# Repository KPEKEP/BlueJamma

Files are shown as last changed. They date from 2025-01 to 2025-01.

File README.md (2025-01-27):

# Arcade Bluetooth Controller Adapter "BlueJamma"

## Overview
This project provides a hardware and software solution to add Bluetooth gamepad support to Jamma/Chamma arcade boards (like Pandora Box), while maintaining the original physical controls functionality. The adapter allows connecting up to 2 Bluetooth gamepads simultaneously with the existing control panel.

The device is built around the ESP32-C3 SuperMini development board, which provides an excellent balance of size, features, and cost. The control program is based on the BluePad32 library and can be found in the `sketch` folder of this repository.

## Features
- Supports up to 2 Bluetooth gamepads simultaneously
- Maintains original control panel functionality
- Compatible with Jamma/Chamma arcade boards
- Easy installation and setup
- Open-source hardware and software

## Hardware
The project uses the ESP32-C3 SuperMini form factor for its compact size and built-in USB capabilities. A complete list of required components and materials can be found in the interactive [Bill of Materials](bom/ibom.html).

The PCB design incorporates elements from the [JammaKludge project](https://github.com/estechnical/jammakludge) by estechnical, which provided valuable reference for the Jamma connector implementation.

## PCB Design
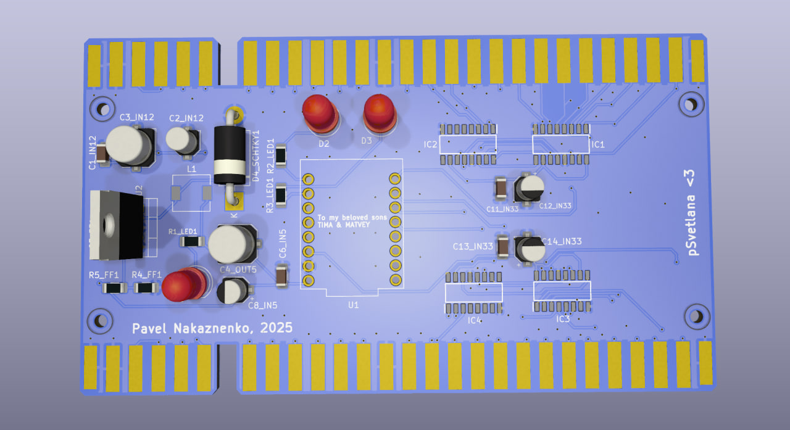
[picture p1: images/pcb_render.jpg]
PCB Front Render

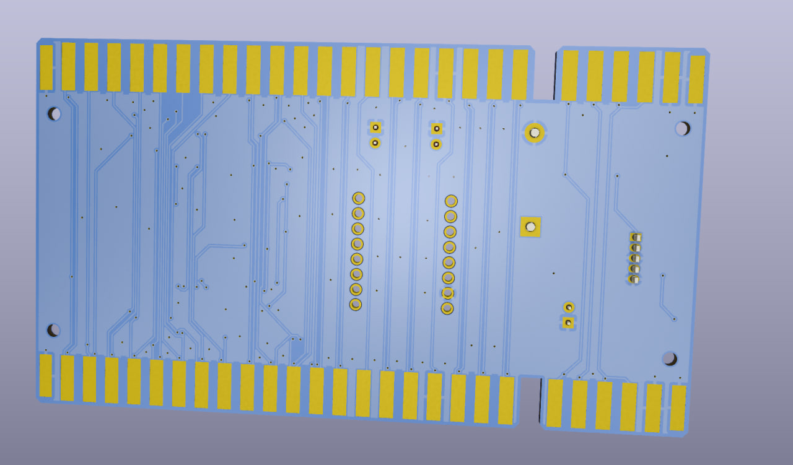
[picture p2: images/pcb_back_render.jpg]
PCB Back Render


## Enclosure Design
Check out the 3D render of the enclosure design:
https://github.com/KPEKEP/BlueJamma/raw/main/enclosure/export/rc3/rc3_v1.avi

STEP files for the enclosure are available in the [enclosure/export/rc3/](enclosure/export/rc3/) folder.

## Assembled Device
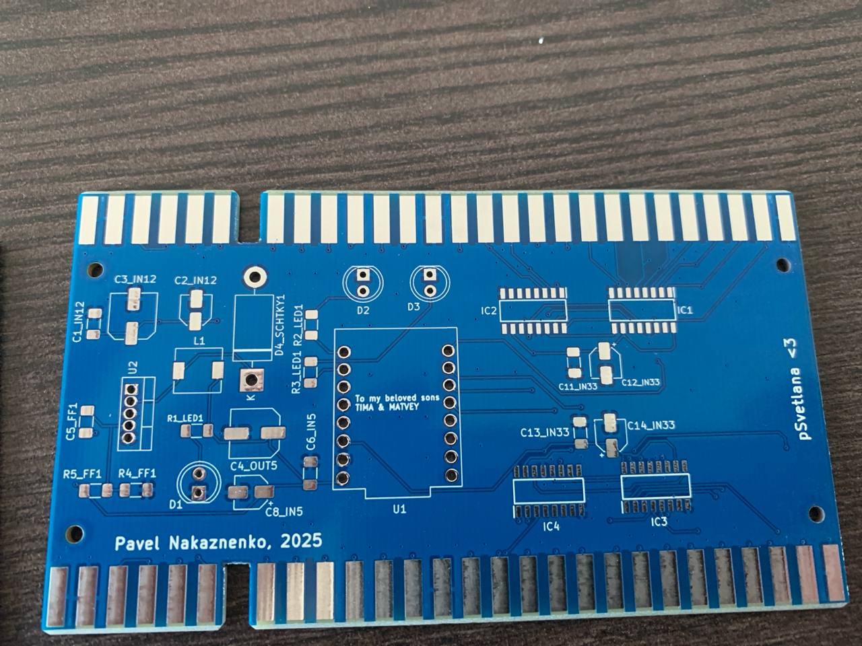
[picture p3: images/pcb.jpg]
Manufactured PCB

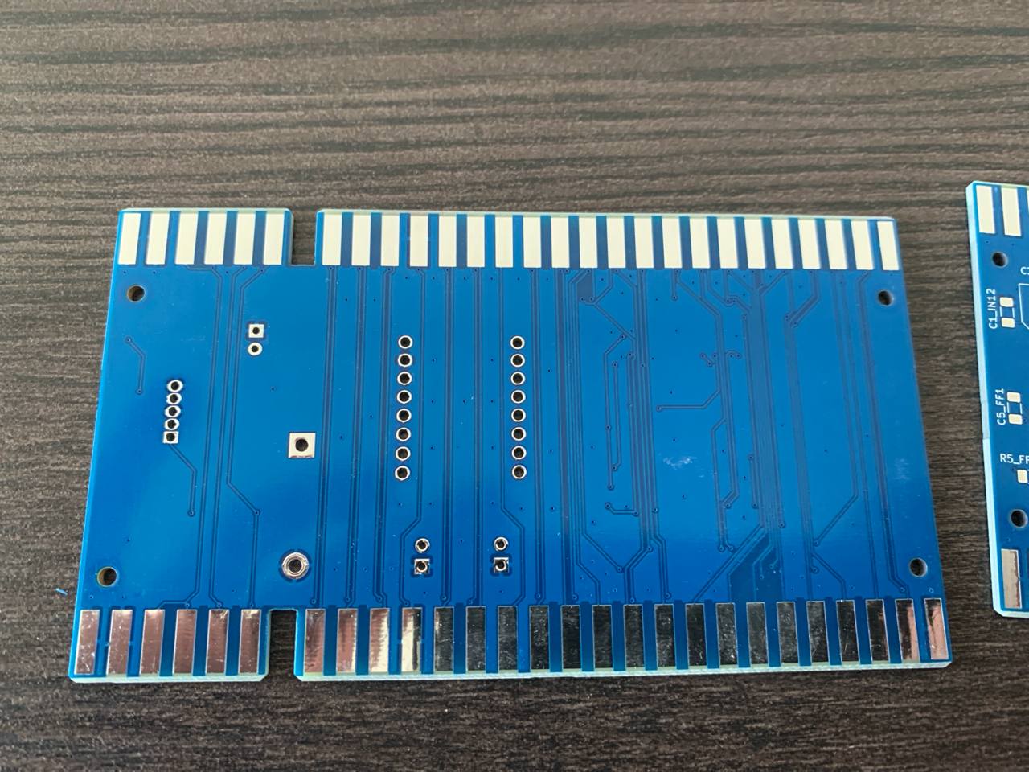
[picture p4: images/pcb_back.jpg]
Manufactured PCB Back

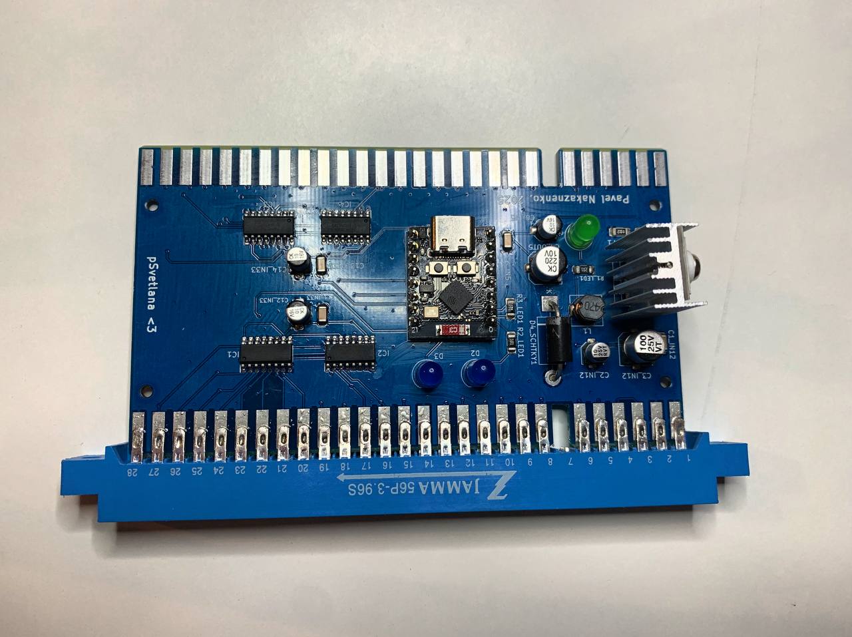
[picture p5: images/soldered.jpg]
Soldered Device

Assembled device: https://github.com/KPEKEP/BlueJamma/raw/main/images/assembled.MOV

Watch a demo of the device working with Bluetooth controllers:
https://github.com/KPEKEP/BlueJamma/raw/main/images/demo.mp4

## Risk Disclaimer
### ATTENTION: The device was tested only with Pandora Box, which is a Chamma board. Jamma boards are not tested yet.
### Chamma and Jamma compatibility
### IMPORTANT: The additional kicker harnesses are not supported yet.

BlueJamma was designed to be a pass-through between the arcade board and physical controls or whatever is connected next. When no input is coming from gamepads, regardless of their connection status, the system behaves as it would be a straight connection between the arcade board and physical controllers.
If an arcade board has Chamma (6-button), or regular Jamma (3-button) interface, it should work.
Please refer to the image of the layout below (side by side of top and bottom side of the PCB) and pay attention to the traces between 25,26,27,C,D,E on the right side of the PCB.

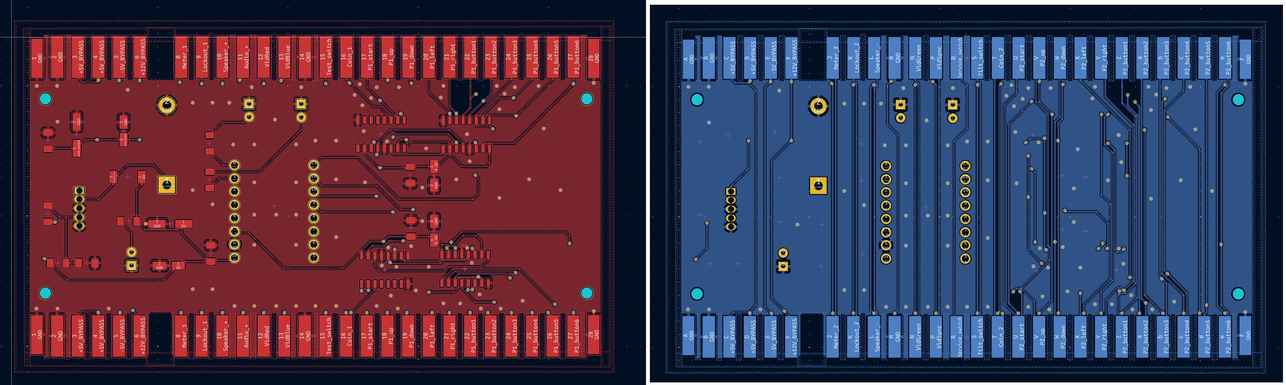
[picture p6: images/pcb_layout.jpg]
PCB Layout


**USE AT YOUR OWN RISK**: The hardware and software in this project are provided "as is", without warranty of any kind, express or implied. The creators and contributors of this project accept no responsibility or liability for any damage, injury, or loss resulting from the use of this project's hardware, software, or documentation.

- We are not responsible for any damage to your arcade board, control panel, or other equipment
- Modify your hardware at your own risk
- Always verify connections and power requirements before use

### Components Attribution
This project uses:
- Open-source libraries and components, all properly credited in the source code
- Originally written code and hardware designs
- Third-party libraries used under their respective licenses (see Dependencies section)

### Non-Commercial Use License
This project is released under a Non-Commercial Use License. You are free to:
- Use this project for personal, non-commercial purposes
- Modify and adapt the code for personal use
- Share the project with others, provided you maintain the same license

You may NOT:
- Use this project for commercial purposes
- Sell products based on this project
- Include this project in commercial applications

## TODO
- [ ] Add kicker harness support
- [ ] Add a shadow-line for the top and bottom parts of the enclosure
- [ ] Test with Jamma board and different harness combinations
- [ ] Test video signal quality with\without BlueJamma. Some decoupling circuitry might be need.
      
## Authors and Acknowledgment
Pavel Nakaznenko, 2025

This project relies on and gratefully acknowledges the following tools and projects:

- [BluePad32](https://github.com/ricardoquesada/bluepad32) - The excellent Bluetooth gamepad support library that powers the controller functionality
- [ESP32-C3](https://www.espressif.com/en/products/socs/esp32-c3) - The RISC-V based microcontroller from Espressif
- [Arduino IDE](https://www.arduino.cc/en/software) - The development environment used for programming
- [KiCad](https://www.kicad.org/) - The open-source software used for electronic design
- [JLCPCB](https://jlcpcb.com/) - PCB manufacturing and assembly services
- [JammaKludge](https://github.com/estechnical/jammakludge) - Reference materials for Jamma connector implementation

Special thanks to all the open-source contributors and communities behind these projects.

---

Remember: This project is for non-commercial use only. All modifications and usage are at your own risk. 

LICENSE: [CC BY-NC-SA 4.0](https://creativecommons.org/licenses/by-nc-sa/4.0/)

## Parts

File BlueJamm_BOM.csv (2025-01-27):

Reference | Value | Footprint | Qty | Description
C1_IN12 | 0.1u | Capacitor_SMD:C_1206_3216Metric_Pad1.33x1.80mm_HandSolder | 1
C2_IN12 | 10u | Capacitor_SMD:C_Elec_4x5.4 | 1
C3_IN12 | 100u | Capacitor_SMD:C_Elec_6.3x5.4 | 1 | Polarized capacitor
C4_OUT5 | 220u | Capacitor_SMD:C_Elec_6.3x7.7 | 1 | Polarized capacitor
C5_FF1 | 10n | Capacitor_SMD:C_1206_3216Metric_Pad1.33x1.80mm_HandSolder | 1 | Unpolarized capacitor
C6_IN5 | 0.1u | Capacitor_SMD:C_1206_3216Metric_Pad1.33x1.80mm_HandSolder | 1
C8_IN5 | 10u | Capacitor_SMD:CP_Elec_4x5.4 | 1
C11_IN33 | 0.1u | Capacitor_SMD:C_1206_3216Metric_Pad1.33x1.80mm_HandSolder | 1
C12_IN33 | 10u | Capacitor_SMD:CP_Elec_4x5.4 | 1
C13_IN33 | 0.1u | Capacitor_SMD:C_1206_3216Metric_Pad1.33x1.80mm_HandSolder | 1
C14_IN33 | 10u | Capacitor_SMD:CP_Elec_4x5.4 | 1
Conn1 | jamma | symbols_fps:JAMMA-56 | 1
Conn2 | jamma | symbols_fps:JAMMA-56_inverted | 1
D1 | LED_5mm | LED_THT:LED_D5.0mm | 1 | Common 5mm diameter LED
D2 | LED_5mm | LED_THT:LED_D5.0mm | 1 | Common 5mm diameter LED
D3 | LED_5mm | LED_THT:LED_D5.0mm | 1 | Common 5mm diameter LED
D4_SCHTKY1 | 1n5822 | Diode_THT:D_DO-201AD_P15.24mm_Horizontal | 1 | 40V 3A Schottky Barrier Rectifier Diode, DO-201AD
IC1 | 74HC595D | symbols_fps:SOIC127P600X175-16N | 1 | IC SHIFT REGISTER 8BIT 16SOP
IC2 | 74HC595D | symbols_fps:SOIC127P600X175-16N | 1 | IC SHIFT REGISTER 8BIT 16SOP
IC3 | 74HC595D | symbols_fps:SOIC127P600X175-16N | 1 | IC SHIFT REGISTER 8BIT 16SOP
IC4 | 74HC595D | symbols_fps:SOIC127P600X175-16N | 1 | IC SHIFT REGISTER 8BIT 16SOP
L1 | 47u | Inductor_SMD:L_6.3x6.3_H3 | 1 | Inductor
R1_LED1 | 200 | Resistor_SMD:R_1206_3216Metric_Pad1.30x1.75mm_HandSolder | 1 | Resistor
R2_LED1 | 100 | Resistor_SMD:R_1206_3216Metric_Pad1.30x1.75mm_HandSolder | 1 | Resistor
R3_LED1 | 100 | Resistor_SMD:R_1206_3216Metric_Pad1.30x1.75mm_HandSolder | 1 | Resistor
R4_FF1 | 1k | Resistor_SMD:R_1206_3216Metric_Pad1.30x1.75mm_HandSolder | 1 | Resistor
R5_FF1 | 3k | Resistor_SMD:R_1206_3216Metric_Pad1.30x1.75mm_HandSolder | 1 | Resistor
U1 | ESP32-C3_SUPERMINI | symbols_fps:MODULE_ESP32-C3_SUPERMINI | 1
U2 | LM2596T-ADJ | Package_TO_SOT_THT:TO-220-5_Vertical_Pavel | 1 | Adjustable 3A 150kHz Step-Down Voltage Regulator, TO-220

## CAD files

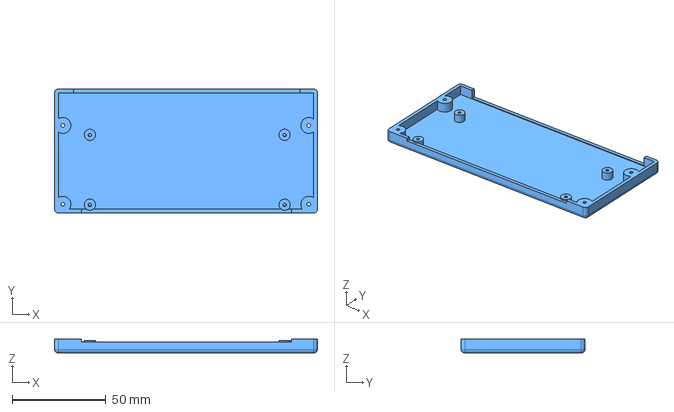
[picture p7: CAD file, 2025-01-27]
enclosure/export/rc3/BottomPanel.step
140.1 x 66.0 x 7.50 mm

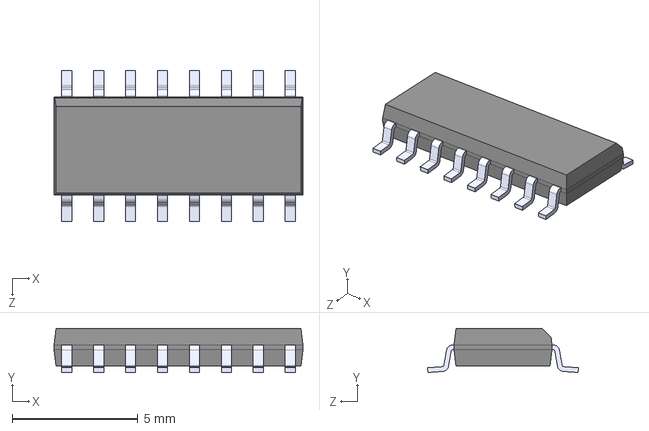
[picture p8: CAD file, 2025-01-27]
symbols_fps/74HC595D.step
9.90 x 1.75 x 6.00 mm

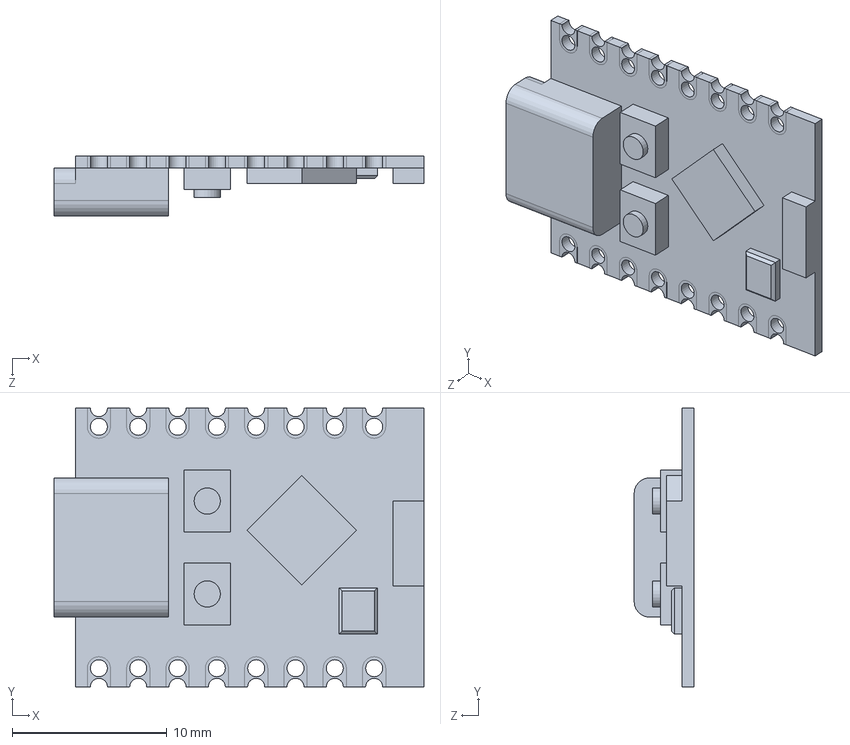
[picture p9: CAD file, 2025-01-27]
symbols_fps/esp32-c3-super-mini-1.snapshot.1/ESP32-C3 SuperMini.SLDPRT
23.9 x 18.0 x 3.86 mm

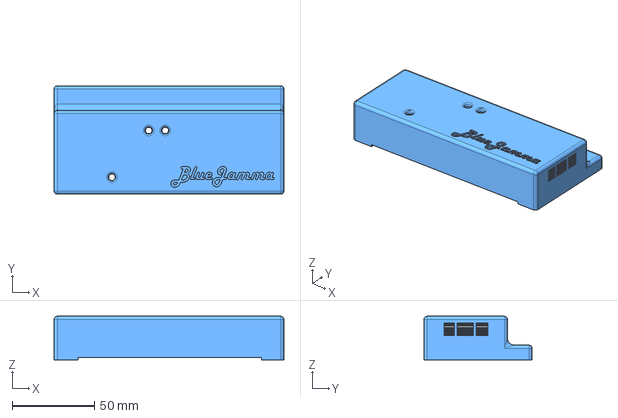
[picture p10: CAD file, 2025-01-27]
enclosure/export/rc3/TopPanel.step
140.1 x 66.0 x 26.5 mm

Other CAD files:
symbols_fps/esp32-c3-super-mini-1.snapshot.1/ESP32-C3 SuperMini.obj

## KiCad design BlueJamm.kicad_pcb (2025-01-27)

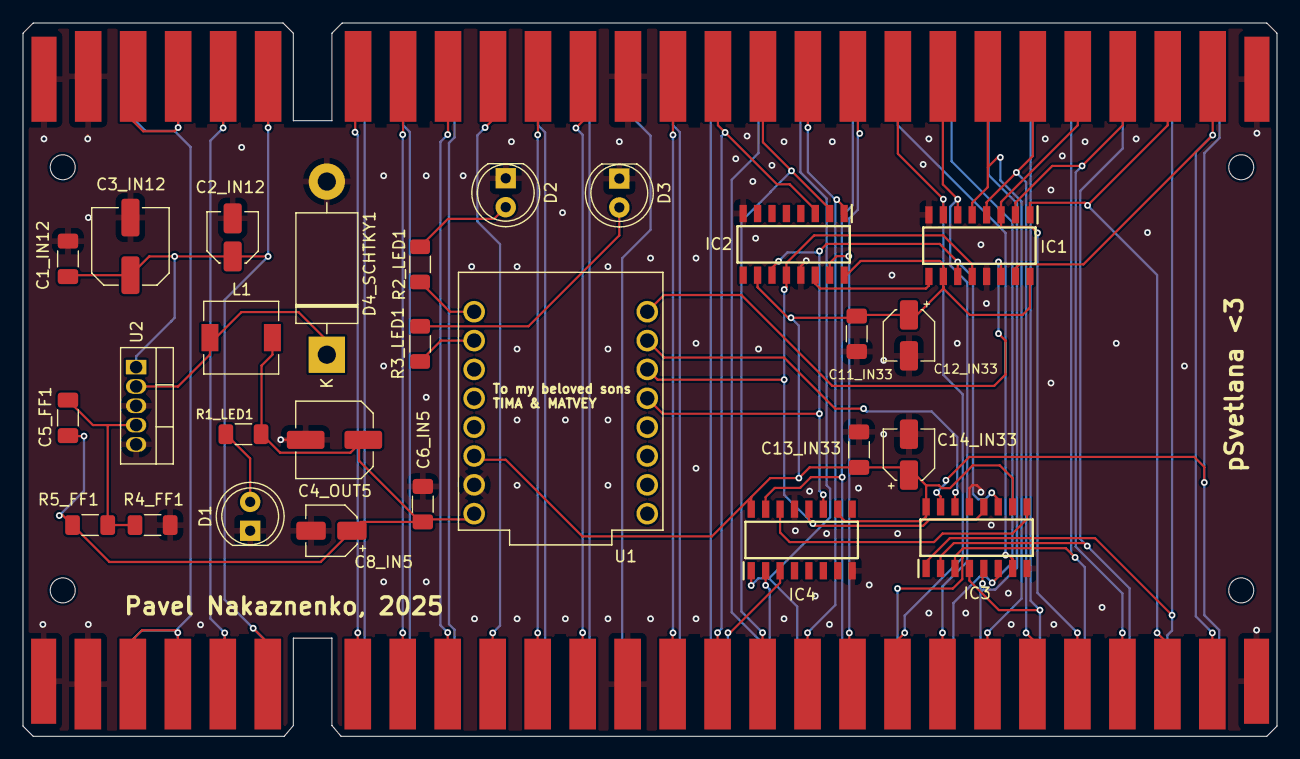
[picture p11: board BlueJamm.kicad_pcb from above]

Board: 2 copper layers, 110.4 x 62.8 mm, 33 parts (0 on the bottom side), 57 nets.

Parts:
C1_IN12, C6_IN5, C11_IN33, C13_IN33: 0.1u; C_1206_3216Metric_Pad1.33x1.80mm_HandSolder
C2_IN12: 10u; C_Elec_4x5.4
C3_IN12: 100u; C_Elec_6.3x5.4
C4_OUT5: 220u; C_Elec_6.3x7.7
C5_FF1: 10n; C_1206_3216Metric_Pad1.33x1.80mm_HandSolder
C8_IN5, C12_IN33, C14_IN33: 10u; CP_Elec_4x5.4
Conn1: jamma; JAMMA-56
Conn2: jamma; JAMMA-56_inverted
D1, D2, D3: LED_5mm; LED_D5.0mm
D4_SCHTKY1: 1n5822; D_DO-201AD_P15.24mm_Horizontal
H1, H2, H3, H4: MountingHole_2.2mm_M2
IC1, IC2, IC3, IC4: 74HC595D; SOIC127P600X175-16N
L1: 47u; L_6.3x6.3_H3
R1_LED1: 200; R_1206_3216Metric_Pad1.30x1.75mm_HandSolder
R2_LED1, R3_LED1: 100; R_1206_3216Metric_Pad1.30x1.75mm_HandSolder
R4_FF1: 1k; R_1206_3216Metric_Pad1.30x1.75mm_HandSolder
R5_FF1: 3k; R_1206_3216Metric_Pad1.30x1.75mm_HandSolder
U1: ESP32-C3_SUPERMINI; MODULE_ESP32-C3_SUPERMINI
U2: LM2596T-ADJ; TO-220-5_Vertical_Pavel

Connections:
/3.3V: C11_IN33.1, C12_IN33.1, C13_IN33.1, C14_IN33.1, IC1.10 (~MR), IC1.16 (VCC), IC2.10 (~MR), IC2.16 (VCC), IC3.10 (~MR), IC3.16 (VCC), IC4.10 (~MR), IC4.16 (VCC), U1.3.3 (3V3)
/5V: C4_OUT5.1, C5_FF1.2, C6_IN5.1, C8_IN5.1, L1.2, R1_LED1.1, R5_FF1.1, U1.5V
/+5V_BYPASS: Conn1.3 (+5v), Conn1.4 (+5v), Conn1.C (+5v), Conn1.D (+5v), Conn2.3 (+5v), Conn2.4 (+5v), Conn2.C (+5v), Conn2.D (+5v)
/+12V_BYPASS: C1_IN12.1, C2_IN12.1, C3_IN12.1, Conn1.6 (+12v), Conn1.F (+12v), Conn2.6 (+12v), Conn2.F (+12v), U2.1 (VIN)
/-5V_BYPASS: Conn1.5 (-5v), Conn1.E (-5v), Conn2.5 (-5v), Conn2.E (-5v)
/Audio_+: Conn1.11 (Audio_+), Conn2.11 (Audio_+)
/Coin_1: Conn1.16 (Coin_1), Conn2.16 (Coin_1), IC2.3 (Q3)
/Coin_2: Conn1.T (Coin2), Conn2.T (Coin2), IC4.3 (Q3)
/Lockout_1: Conn1.9 (Lockout_1), Conn2.9 (Lockout_1)
/Lockout_2: Conn1.K (Lockout_2), Conn2.K (Lockout_2)
/Meter_1: Conn1.8 (Meter_1), Conn2.8 (Meter_1)
/Meter_2: Conn1.J (Meter_2), Conn2.J (Meter_2)
/P1_button1: Conn1.22 (P1_button1), Conn2.22 (P1_button1), IC1.5 (Q5)
/P1_button2: Conn1.23 (P1_button2), Conn2.23 (P1_button2), IC1.4 (Q4)
/P1_button3: Conn1.24 (P1_button3), Conn2.24 (P1_button3), IC1.3 (Q3)
/P1_button4: Conn1.25 (P1_button4), Conn2.25 (P1_button4), IC1.2 (Q2)
/P1_button5: Conn1.26 (P1_button5), Conn2.26 (P1_button5), IC1.1 (Q1)
/P1_button6: Conn1.27 (P1_button6), Conn2.27 (P1_button6), IC1.15 (Q0)
/P1_connected: R2_LED1.1, U1.0 (GPIO0)
/P1_down: Conn1.19 (P1_down), Conn2.19 (P1_down), IC2.15 (Q0)
/P1_left: Conn1.20 (P1_left), Conn2.20 (P1_left), IC1.7 (Q7)
/P1_right: Conn1.21 (P1_right), Conn2.21 (P1_right), IC1.6 (Q6)
/P1_start: Conn1.17 (P1_start), Conn2.17 (P1_start), IC2.2 (Q2)
/P1_up: Conn1.18 (P1_up), Conn2.18 (P1_up), IC2.1 (Q1)
/P2_button1: Conn1.Z (P2_button1), Conn2.Z (P2_button1), IC3.5 (Q5)
/P2_button2: Conn1.a (P2_button2), Conn2.a (P2_button2), IC3.4 (Q4)
/P2_button3: Conn1.b (P2_button3), Conn2.b (P2_button3), IC3.3 (Q3)
/P2_button4: Conn1.c (P2_button4), Conn2.c (P2_button4), IC3.2 (Q2)
/P2_button5: Conn1.d (P2_button5), Conn2.d (P2_button5), IC3.1 (Q1)
/P2_button6: Conn1.e (P2_button6), Conn2.e (P2_button6), IC3.15 (Q0)
/P2_connected: R3_LED1.1, U1.1 (GPIO1)
/P2_down: Conn1.W (P2_down), Conn2.W (P2_down), IC4.15 (Q0)
/P2_left: Conn1.X (P2_left), Conn2.X (P2_left), IC3.7 (Q7)
/P2_right: Conn1.Y (P2_right), Conn2.Y (P2_right), IC3.6 (Q6)
/P2_start: Conn1.U (P2_start), Conn2.U (P2_start), IC4.2 (Q2)
/P2_up: Conn1.V (P2_up), Conn2.V (P2_up), IC4.1 (Q1)
/RCLK: IC1.12 (STCP), IC2.12 (STCP), IC3.12 (STCP), IC4.12 (STCP), U1.10 (GPIO10)
/SER_P1: IC1.14 (DS), U1.21 (GPIO21)
/SER_P2: IC3.14 (DS), U1.20 (GPIO20)
/SRCLK: IC1.11 (SHCP), IC2.11 (SHCP), IC3.11 (SHCP), IC4.11 (SHCP), U1.9 (GPIO9)
/Service_switch: Conn1.R (Service_switch), Conn2.R (Service_switch)
/Speaker_+: Conn1.10 (Speaker_+), Conn2.10 (Speaker_+)
/Speaker_-: Conn1.L (Speaker_-), Conn2.L (Speaker_-)
/Test_switch: Conn1.15 (Test_switch), Conn2.15 (Test_switch)
/Tilt_switch: Conn1.S (Tilt_switch), Conn2.S (Tilt_switch)
/VidBlue: Conn1.13 (Video_blue), Conn2.13 (Video_blue)
/VidGreen: Conn1.N (Video_green), Conn2.N (Video_green)
/VidRed: Conn1.12 (Video_red), Conn2.12 (Video_red)
/VidSync: Conn1.P (Video_sync), Conn2.P (Video_sync)
GND: C1_IN12.2, C2_IN12.2, C3_IN12.2, C4_OUT5.2, C6_IN5.2, C8_IN5.2, C11_IN33.2, C12_IN33.2, C13_IN33.2, C14_IN33.2, Conn1.1 (Gnd), Conn1.2 (Gnd), Conn1.14 (Video_gnd), Conn1.28 (Gnd), Conn1.A (Gnd), Conn1.B (Gnd), Conn1.M (Audio_gnd), Conn1.f (Gnd), Conn2.1 (Gnd), Conn2.2 (Gnd), Conn2.14 (Video_gnd), Conn2.28 (Gnd), Conn2.A (Gnd), Conn2.B (Gnd), Conn2.M (Audio_gnd), Conn2.f (Gnd), D1.1, D2.1, D3.1, D4_SCHTKY1.2 (A), IC1.8 (GND), IC1.13 (~OE), IC2.8 (GND), IC2.13 (~OE), IC3.8 (GND), IC3.13 (~OE), IC4.8 (GND), IC4.13 (~OE), R4_FF1.1, U1.G (GND), U2.3 (GND), U2.5 (~ON/OFF)
unnamed: D1.2, R1_LED1.2
unnamed: D2.2, R2_LED1.2
unnamed: D3.2, R3_LED1.2
unnamed: D4_SCHTKY1.1 (K), L1.1, U2.2 (OUT)
unnamed: IC1.9 (Q7S), IC2.14 (DS)
unnamed: IC3.9 (Q7S), IC4.14 (DS)
unnamed: C5_FF1.1, R4_FF1.2, R5_FF1.2, U2.4 (FB)

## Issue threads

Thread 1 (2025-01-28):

Pinouts for typical Expansion IO (aka kick) Connectors

twistedsymphony, 2025-01-28:
Since the topic on Reddit got locked I figured I'd post here.
I covered the JAMMA standard but what I didn't cover earlier was the typical expansion io (aka kick) connector information.

some good overall info here: https://wiki.arcadeotaku.com/w/CPS1,_CPS2_%26_CPS3_Connectors

official documents:
CPS1 style kick harness
page 16: https://archive.org/details/arcademanual_street-fighter-2/page/n15/mode/2up

note that:
"kick light" = button 4
"kick middle" = button 5
"kick heavy" = button 6

CPS2 style kick harness:
page 4: https://archive.org/details/arcademanual_Super_Street_Fighter_IIThe_New_Challengers/page/n3/mode/2up

KPEKEP, 2025-01-28:
Thank you very much for the info! The reddit post got deleted and locked unfortunately (because it is a custom expansion).
So I also will quote your comment here for future reference when I start implementing kicker harnsess support
You said:

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

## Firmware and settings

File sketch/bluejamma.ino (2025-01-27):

#include <Bluepad32.h>

// Configuration
#define DEBUG_MODE 0  // Set to 1 to enable debug logging (temporarily enabled for troubleshooting)

// Pin Definitions
namespace Pins {
constexpr uint8_t R1_SER = 21;   // Serial input for the first of two shift-registers of Player 1 input
constexpr uint8_t R2_SER = 20;   // Serial input for the first of two shift-registers of Player 2 input
constexpr uint8_t R1_RCLK = 10;  // All shift registers share the same RCLK (Storage register clock)
constexpr uint8_t R1_SRCLK = 9;  // All shift registers share the same SRCLK (Shift register clock)
constexpr uint8_t LED_P1 = 0;    // LED for Player 1 connection status
constexpr uint8_t LED_P2 = 1;    // LED for Player 2 connection status
}

// Constants
namespace Constants {
constexpr int MAX_GAMEPADS = 2;          // Maximum number of supported gamepads
constexpr int STICK_DEAD_ZONE = 64;     // Analog stick dead zone value (0-512)
}

// Debug logging macro for conditional debug output
#define DEBUG_LOG(...) \
  do { \
    if (DEBUG_MODE) Serial.printf(__VA_ARGS__); \
  } while (0)

/**
 * @brief Manages a pair of 8-bit shift registers for gamepad output
 * 
 * This class handles the low-level communication with the shift registers,
 * converting gamepad states into serial data for output.
 */
class ShiftRegister {
public:
  ShiftRegister(uint8_t ser, uint8_t rclk, uint8_t srclk)
    : serPin_(ser), rclkPin_(rclk), srclkPin_(srclk), currentValue_{ 0, 0 } {
    initialize();
  }

  // Updates the internal state of the shift registers
  void update(uint8_t highByte, uint8_t lowByte) {
    currentValue_[0] = highByte;
    currentValue_[1] = lowByte;
  }

  // Sets the serial input bit for the shift register
  void setBit(bool value) {
    digitalWrite(serPin_, value);
  }

  // Getters for current register values
  uint8_t getHighByte() const { return currentValue_[0]; }
  uint8_t getLowByte() const { return currentValue_[1]; }

private:
  void initialize() {
    pinMode(serPin_, OUTPUT);
    pinMode(rclkPin_, OUTPUT);
    pinMode(srclkPin_, OUTPUT);
    digitalWrite(serPin_, LOW);
  }

  const uint8_t serPin_;    // Serial data input pin
  const uint8_t rclkPin_;   // Storage register clock pin
  const uint8_t srclkPin_;  // Shift register clock pin
  uint8_t currentValue_[2]; // Current register values: [0] = high byte, [1] = low byte
};

/**
 * @brief Main class handling gamepad connections and input processing
 * 
 * Manages Bluetooth gamepad connections, processes input data, and
 * outputs the processed states to shift registers.
 */
class GamepadManager {
public:
  GamepadManager()
    : reg1_(Pins::R1_SER, Pins::R1_RCLK, Pins::R1_SRCLK),
      reg2_(Pins::R2_SER, Pins::R1_RCLK, Pins::R1_SRCLK),
      connectedGamepads_(0) {
    initialize();
  }

  void setup() {
    setupBluePad32();
    initializeOutputs();
    setupLEDs();
    DEBUG_LOG("GamepadManager setup complete\n");
  }

  // Main update function - processes controller input
  void update() {
    if (BP32.update()) {
      processControllers();
    }
    updateLEDs();
  }

  // Static callback handlers for controller events
  static void onConnectedController(ControllerPtr ctl) {
    instance().handleControllerConnection(ctl);
  }

  static void onDisconnectedController(ControllerPtr ctl) {
    instance().handleControllerDisconnection(ctl);
  }

  // Singleton instance accessor
  static GamepadManager& instance() {
    static GamepadManager instance;
    return instance;
  }

private:
  ShiftRegister reg1_, reg2_;
  ControllerPtr controllers_[Constants::MAX_GAMEPADS];
  uint16_t lastStates_[Constants::MAX_GAMEPADS];
  int connectedGamepads_;       // Number of currently connected gamepads

  void initialize() {
    for (auto& controller : controllers_) {
      controller = nullptr;
    }
    for (auto& state : lastStates_) {
      state = 0xFFFF;  // All bits set to 1 (inactive)
    }
    DEBUG_LOG("GamepadManager initialized\n");
  }

  void setupBluePad32() {
    BP32.setup(&onConnectedController, &onDisconnectedController);
    BP32.enableVirtualDevice(false);  // Disable virtual gamepad device
    DEBUG_LOG("Bluepad32 setup complete\n");
  }

  void setupLEDs() {
    pinMode(Pins::LED_P1, OUTPUT);
    pinMode(Pins::LED_P2, OUTPUT);
    digitalWrite(Pins::LED_P1, LOW);
    digitalWrite(Pins::LED_P2, LOW);
  }

  void updateLEDs() {
    digitalWrite(Pins::LED_P1, controllers_[0] != nullptr ? HIGH : LOW);
    digitalWrite(Pins::LED_P2, controllers_[1] != nullptr ? HIGH : LOW);
  }

  // Clears output for a specific player
  void clearPlayerOutput(int ctlIndex) {
    lastStates_[ctlIndex] = 0xFFFF;
    updateRegisters();
    DEBUG_LOG("Cleared output for player %d\n", ctlIndex + 1);
  }

  void initializeOutputs() {
    for (int i = 0; i < Constants::MAX_GAMEPADS; i++) {
      clearPlayerOutput(i);
    }
  }

  // Updates shift registers with current gamepad states
  void updateRegisters() {
    // First shift out the high byte (bits 15-8)
    for (int i = 7; i >= 0; i--) {
      reg1_.setBit(!!(lastStates_[0] & (1 << (i + 8))));
      reg2_.setBit(!!(lastStates_[1] & (1 << (i + 8))));
      
      digitalWrite(Pins::R1_SRCLK, HIGH);
      digitalWrite(Pins::R1_SRCLK, LOW);
    }

    // Then shift out the low byte (bits 7-0)
    for (int i = 7; i >= 0; i--) {
      reg1_.setBit(!!(lastStates_[0] & (1 << i)));
      reg2_.setBit(!!(lastStates_[1] & (1 << i)));
      
      digitalWrite(Pins::R1_SRCLK, HIGH);
      digitalWrite(Pins::R1_SRCLK, LOW);
    }

    // Latch the outputs simultaneously
    digitalWrite(Pins::R1_RCLK, HIGH);
    digitalWrite(Pins::R1_RCLK, LOW);
  }

  // Handles new controller connections
  void handleControllerConnection(ControllerPtr ctl) {
    for (int i = 0; i < Constants::MAX_GAMEPADS; i++) {
      if (controllers_[i] == nullptr) {
        DEBUG_LOG("Controller connected at index=%d\n", i);
        controllers_[i] = ctl;
        configureNewController(ctl, i);
        connectedGamepads_++;
        DEBUG_LOG("Total connected gamepads: %d\n", connectedGamepads_);
        return;
      }
    }
    DEBUG_LOG("No empty slots for new controller\n");
  }

  // Configures newly connected controllers
  void configureNewController(ControllerPtr ctl, int index) {
    auto properties = ctl->getProperties();
    DEBUG_LOG("Controller model: %s, VID=0x%04x, PID=0x%04x\n",
              ctl->getModelName().c_str(),
              properties.vendor_id,
              properties.product_id);

    // Play rumble effect to indicate successful connection
    ctl->playDualRumble(0, 250, 0x80, 0x40);
  }

  // Handles controller disconnections
  void handleControllerDisconnection(ControllerPtr ctl) {
    for (int i = 0; i < Constants::MAX_GAMEPADS; i++) {
      if (controllers_[i] == ctl) {
        DEBUG_LOG("Controller disconnected from index=%d\n", i);
        clearPlayerOutput(i);
        controllers_[i] = nullptr;
        connectedGamepads_--;
        DEBUG_LOG("Total connected gamepads: %d\n", connectedGamepads_);
        return;
      }
    }
  }

  // Main controller input processing loop
  void processControllers() {
    bool needsUpdate = false;
    for (int i = 0; i < Constants::MAX_GAMEPADS; ++i) {
      ControllerPtr controller = controllers_[i];
      if (controller && controller->isConnected()) {
        if (controller->hasData()) {
          if (controller->isGamepad()) {
            processGamepadInput(controller, i);
            needsUpdate = true;
          } else {
            DEBUG_LOG("Unsupported controller type\n");
          }
        }
      }
    }
    if (needsUpdate) {
      updateRegisters();
    }
  }

  // Processes input from a single gamepad
  void processGamepadInput(ControllerPtr ctl, int ctlIndex) {
    // Output format:
    // [15-12: unused (0000)]
    // [11: select button]
    // [10: start button]
    // [9-6: up/down/left/right]
    // [5-0: action buttons]

    // Process button states (bits 5-0)
    uint16_t buttonStates = mapButtons(ctl->buttons() & 0x3F);
    
    // Process D-pad and left analog stick (bits 9-6)
    uint8_t dpadState = ctl->dpad();
    uint8_t mappedDpad = mapDpadState(dpadState);
    uint8_t mappedLeftStick = mapLeftStickState(ctl->axisX(), ctl->axisY());
    uint16_t directionState = ((mappedDpad | mappedLeftStick) & 0x0F) << 6;

    // Process Start/Select buttons (bits 11-10)
    uint16_t startButton = (ctl->miscStart() ? 1 : 0) << 10;
    uint16_t selectButton = (ctl->miscSelect() ? 1 : 0) << 11;

    // Combine all states
    uint16_t combinedState = buttonStates | directionState | startButton | selectButton;
    
    // Invert for active-low output
    lastStates_[ctlIndex] = ~combinedState;

#if DEBUG_MODE
    logGamepadState(ctl);
#endif
  }

  // Maps analog stick values to digital directions
  static uint8_t mapLeftStickState(int32_t x, int32_t y) {
    uint8_t mapped = 0;
    bitWrite(mapped, 0, x >= Constants::STICK_DEAD_ZONE ? 1 : 0);   // Right
    bitWrite(mapped, 1, x <= -Constants::STICK_DEAD_ZONE ? 1 : 0);  // Left
    bitWrite(mapped, 2, y >= Constants::STICK_DEAD_ZONE ? 1 : 0);  // Up
    bitWrite(mapped, 3, y <= -Constants::STICK_DEAD_ZONE ? 1 : 0);   // Down
    return mapped;
  }

  // Maps D-pad states to consistent bit format
  static uint8_t mapDpadState(uint8_t dpadState) {
    uint8_t mapped = 0;
    bitWrite(mapped, 0, bitRead(dpadState, 2));  // Right
    bitWrite(mapped, 1, bitRead(dpadState, 3));  // Left
    bitWrite(mapped, 2, bitRead(dpadState, 1));  // Up
    bitWrite(mapped, 3, bitRead(dpadState, 0));  // Down
    return mapped;
  }

  static uint16_t mapButtons(uint16_t buttons) {
    uint16_t mapped = 0;
    bitWrite(mapped, 0, bitRead(buttons, 5));
    bitWrite(mapped, 1, bitRead(buttons, 4));
    bitWrite(mapped, 2, bitRead(buttons, 3));
    bitWrite(mapped, 3, bitRead(buttons, 2));
    bitWrite(mapped, 4, bitRead(buttons, 1));
    bitWrite(mapped, 5, bitRead(buttons, 0));
    return mapped;
  }
  // Logs detailed gamepad state for debugging
  static void logGamepadState(ControllerPtr ctl) {
    DEBUG_LOG(
      "idx=%d, dpad: 0x%02x, buttons: 0x%04x, axis L: %4d, %4d, axis R: %4d, %4d, "
      "brake: %4d, throttle: %4d, misc: 0x%02x\n",
      ctl->index(), ctl->dpad(), ctl->buttons(),
      ctl->axisX(), ctl->axisY(), ctl->axisRX(), ctl->axisRY(),
      ctl->brake(), ctl->throttle(), ctl->miscButtons());
  }
};

void setup() {
  Serial.begin(115200);

  // Print firmware information and Bluetooth address
  Serial.printf("Firmware: %s\n", BP32.firmwareVersion());
  const uint8_t* addr = BP32.localBdAddress();
  Serial.printf("BD Addr: %02X:%02X:%02X:%02X:%02X:%02X\n",
                addr[0], addr[1], addr[2], addr[3], addr[4], addr[5]);

  // Initialize the GamepadManager
  GamepadManager::instance().setup();
  
  // Allow time for systems to stabilize
  delay(1000);
  
  Serial.println("v0.70 Started!");
#if DEBUG_MODE
  Serial.println("DEBUG MODE IS ENABLED!");
#endif
}

void loop() {
  // Update the GamepadManager state
  GamepadManager::instance().update();
  
  // Small delay to prevent overwhelming the system
  delay(1);
}

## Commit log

2025-01-27 missing resources
    [ESP32-C3 SuperMini.obj]
2025-01-27 improved enclosure, readme update
    [BottomPanel.step, BottomPanel_rc2.step, TopPanel.step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]
2025-01-27 Jamma and Chamma clarification, pcb layout image
